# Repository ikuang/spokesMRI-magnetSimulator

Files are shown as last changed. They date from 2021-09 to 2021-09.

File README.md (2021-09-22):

# spokesMRI-magnetSimulator
 
 Matlab simulator for magnetic fields generated by 'spokes-and-hub' permanent magnet arrays as presented at ISMRM 2019 [1].
 
 To input magnet geometries and run simulator use:
 ```matlab 
 testMagnet.m
 ```
 
 We have provided [STL](stl) files for a 191 mT magnet constructed using 64 bar magnets (1/2" x 1/8" x 1") from [K&J Magnets](https://www.kjmagnetics.com/proddetail.asp?prod=B82X0).
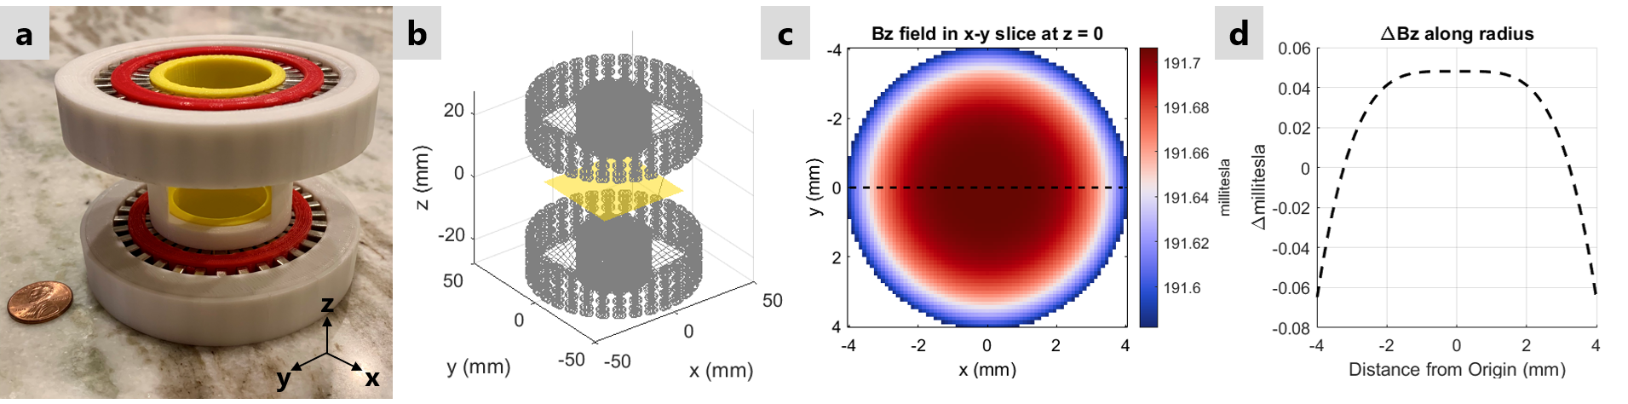
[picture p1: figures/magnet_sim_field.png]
 
 
 We use mechanical tilts from linear actuators to generate gradient fields within the magnet [2]. The actuators and their control boards were purchased from [Actuonix](https://www.actuonix.com/L12-P-Micro-Linear-Actuator-with-Position-Feedback-p/l12-p.htm). Instructions and [DXF](dxf) files for laser cutting acrylic are provided as well.
 
 
 We use an 8-channel STHV800 ultrasound h-bridge driver chip from [STMicroelectronics](https://www.st.com/en/switches-and-multiplexers/sthv800.html) to transmit/receive RF on a solenoid coil [3]. A Teensy 4.0 microcontroller sends RF pulses to the driver. We have provided a sample dithered RF pulse (centered at 8.18MHz with 100kHz bandwidth), Arduino code that controls the pulses and actuator movements, and Eagle PCB layouts for the ultrasound chip board. These files are found in the [signalChain](./signalChain) directory. We use a USB oscilloscope from Pico Technology ([PicoScope 5243D](https://www.picotech.com/oscilloscope/5000/flexible-resolution-oscilloscope)) to capture MR data at the Larmor frequency and perform filtering and downsampling in software. Pico Technology provides open source software development kits for Python and Matlab implementations (https://github.com/picotech). 
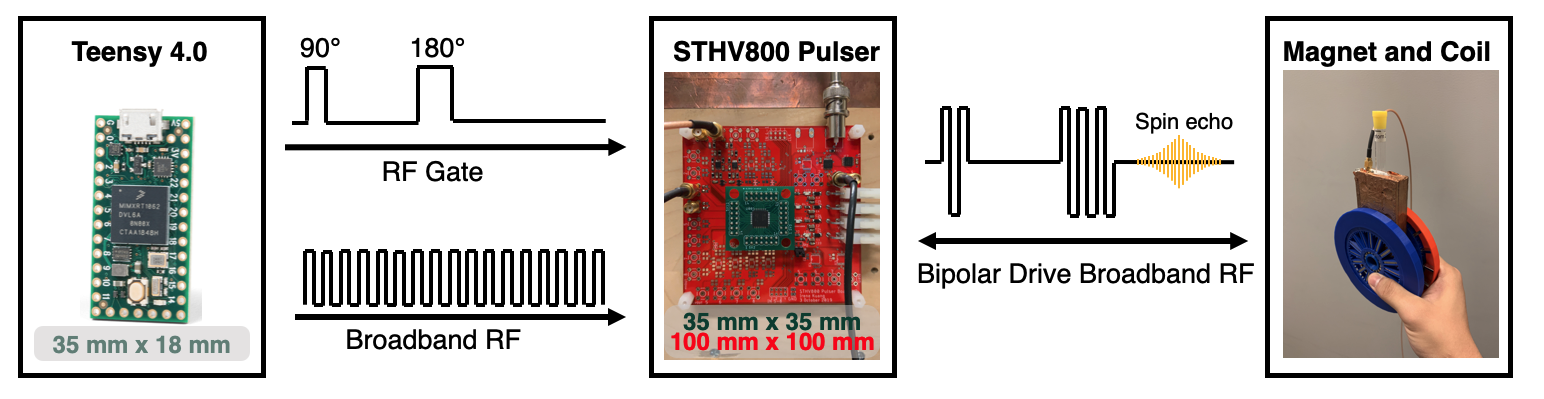
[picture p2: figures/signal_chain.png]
  

## References

[1] Kuang, I., Arango, N., Stockmann, J., Adalsteinsson, E., White, J. <em>Equivalent-Charge-Based Optimization of Spokes-and-Hub Magnets for Hand-Held and Classroom MR Imaging</em>. Proc. Intl. Soc. Mag. Reson. Med., 2019. 

[2] Kuang, I., Stockmann, J., Adalsteinsson, E., White, J. <em>Mechanical Tilt-Induced Gradient Fields for Low-Field Spokes-and-Hub MR Imagers</em>. Proc. Intl. Soc. Mag. Reson. Med., 2021. 

[3] Kuang, I., Arango, N., Stockmann, J., Adalsteinsson, E., White, J. <em>Bloch-Optimized Dithered-Ultrasound-Pulse RF for Low-Field Inhomogeneous Permanent Magnet MR Imagers</em>. Proc. Intl. Soc. Mag. Reson. Med., 2020. 
 
 Plotting functions use perceptually uniform colormaps from https://colorcet.com/

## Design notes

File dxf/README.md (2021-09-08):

# DXF files for laser cutting  
We assembled the linear actuators and magnet with three laser-cut pieces of acrylic (1/4" thick)

1/4"-20 threaded rod were used to loosly align the laser-cut pieces



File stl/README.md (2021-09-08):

# STL files for 3d printing
 
To assemble full magnet, the following pieces are required: 

* innerRing_v3.stl (Quantity: 2)
* outerRing_v2.stl (Quantity: 2)
* hub_outer_v5.stl (Quantity: 2)
* hub_middle_v1.stl (Quantity: 2)
* screw_separator_v4.stl (Quantity: 1)

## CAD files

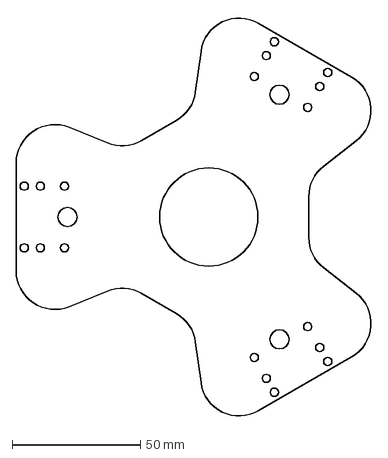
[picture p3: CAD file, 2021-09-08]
dxf/actuatorMiddle_v1.dxf
138.5 x 156.2 mm

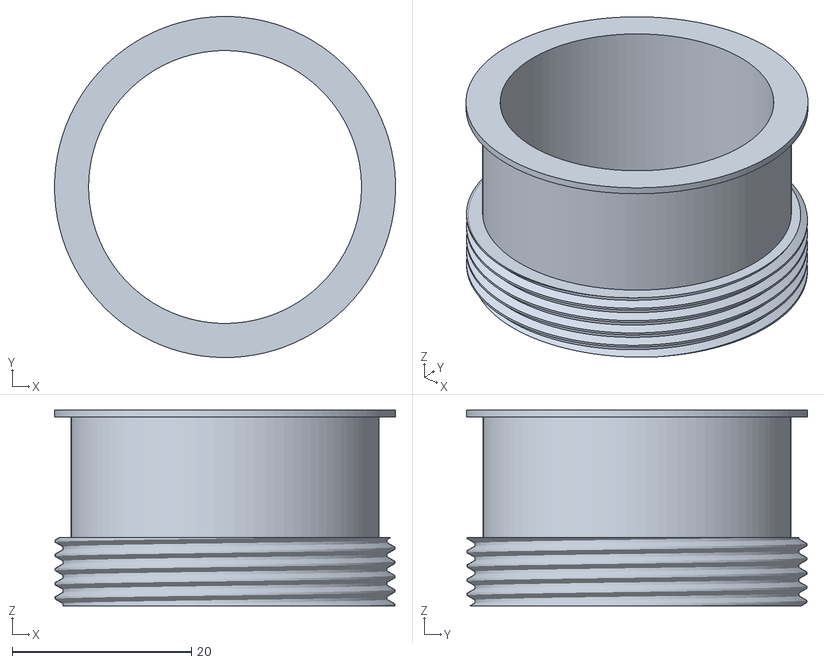
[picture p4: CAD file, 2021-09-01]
stl/innerRing_v3.stl
38.1 x 38.1 x 21.8

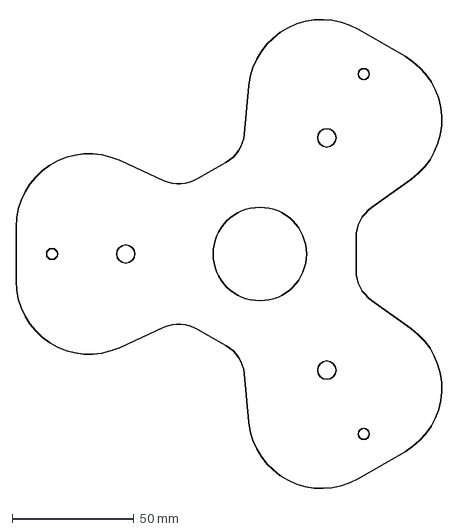
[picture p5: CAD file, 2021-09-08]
dxf/actuatorBottom_v1.dxf
175.1 x 195.1 mm

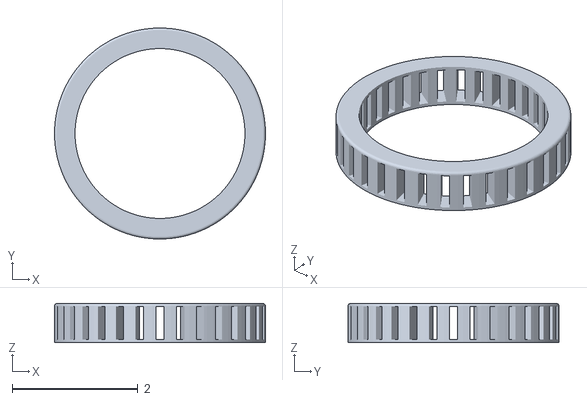
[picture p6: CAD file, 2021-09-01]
stl/hub_outer_v5.stl
3.35 x 3.35 x 0.62

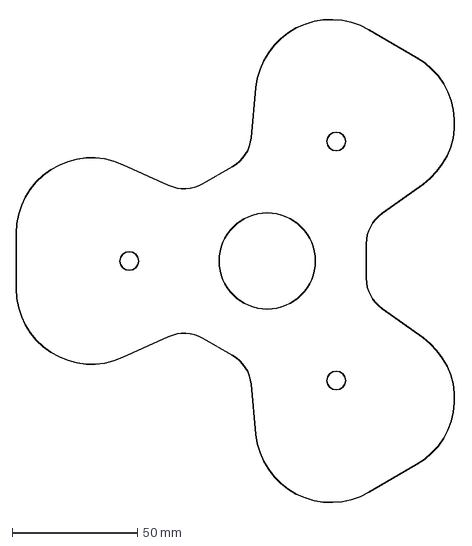
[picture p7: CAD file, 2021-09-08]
dxf/actuatorTop_v1.dxf
175.1 x 195.1 mm

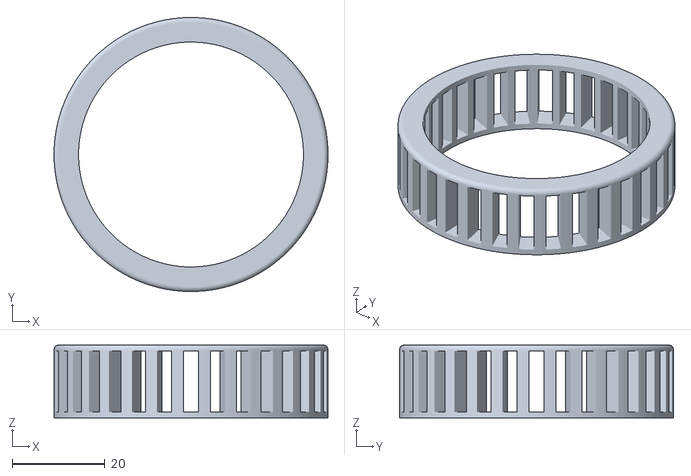
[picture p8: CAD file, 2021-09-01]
stl/hub_middle_v1.stl
59.2 x 59.2 x 15.7

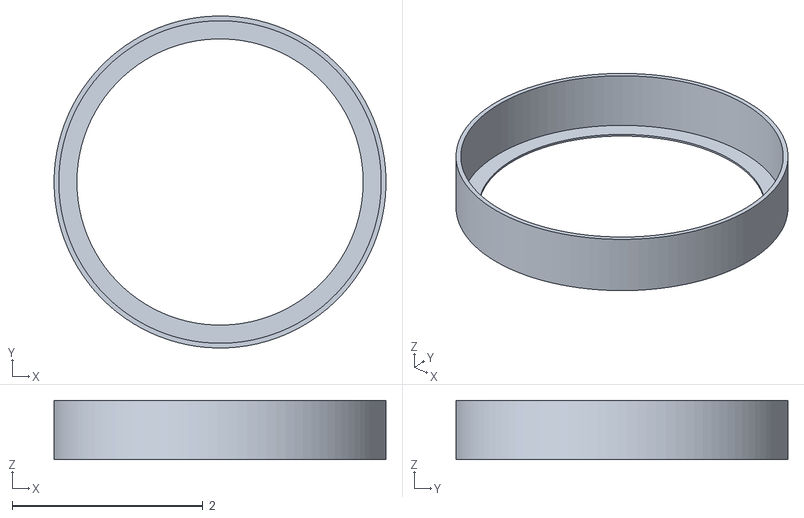
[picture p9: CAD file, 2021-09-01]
stl/outerRing_v2.stl
3.48 x 3.48 x 0.62

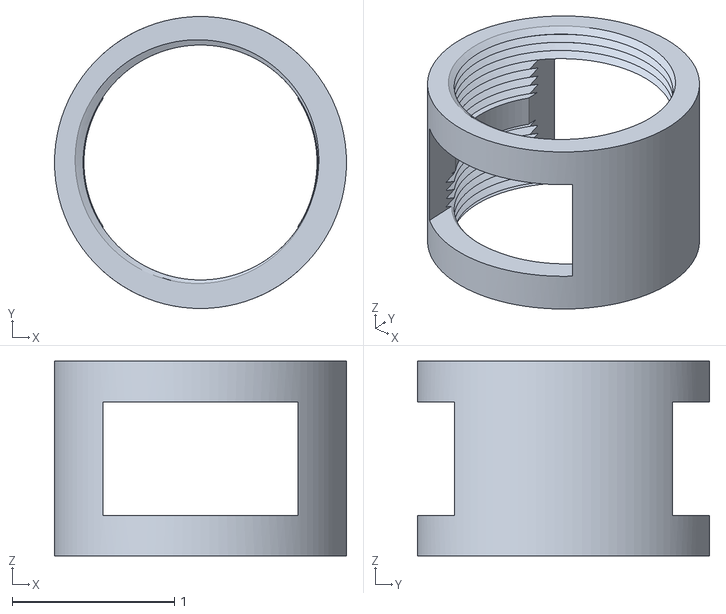
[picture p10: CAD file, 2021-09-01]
stl/screw_separator_v4.stl
1.80 x 1.80 x 1.20

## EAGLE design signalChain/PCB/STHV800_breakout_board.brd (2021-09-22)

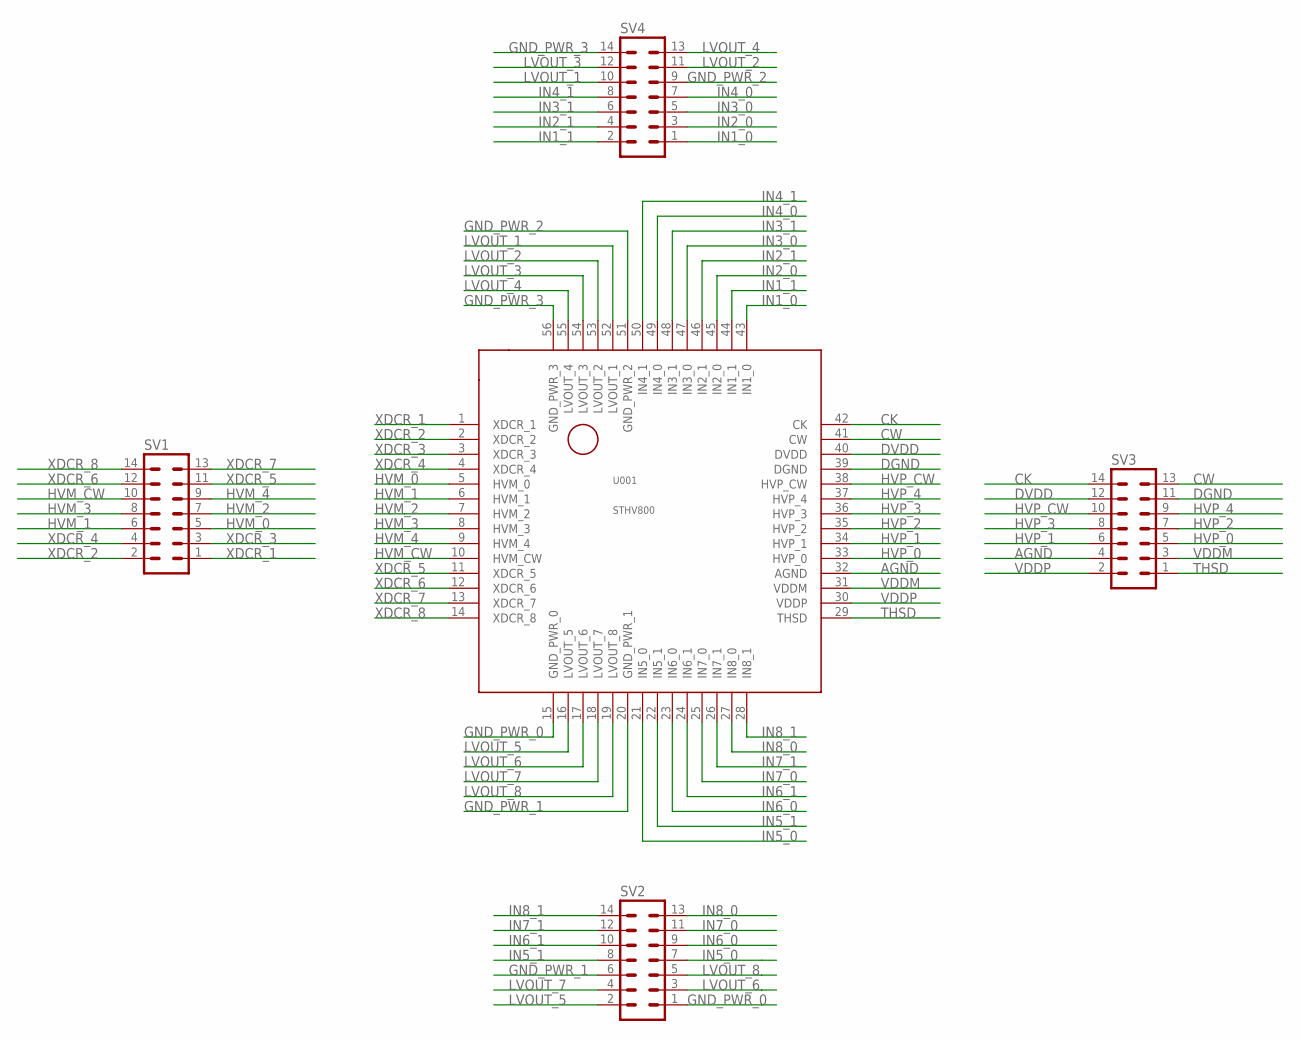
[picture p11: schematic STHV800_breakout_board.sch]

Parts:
SV1, SV2, SV3, SV4: MA07-2
U001: STHV800

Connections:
AGND: SV3.4, U001.32 (AGND)
CK: SV3.14, U001.42 (CK)
CW: SV3.13, U001.41 (CW)
DGND: SV3.11, U001.39 (DGND)
DVDD: SV3.12, U001.40 (DVDD)
GND_PWR_0: SV2.1, U001.15 (GND_PWR_0)
GND_PWR_1: SV2.6, U001.20 (GND_PWR_1)
GND_PWR_2: SV4.9, U001.51 (GND_PWR_2)
GND_PWR_3: SV4.14, U001.56 (GND_PWR_3)
HVM_0: SV1.5, U001.5 (HVM_0)
HVM_1: SV1.6, U001.6 (HVM_1)
HVM_2: SV1.7, U001.7 (HVM_2)
HVM_3: SV1.8, U001.8 (HVM_3)
HVM_4: SV1.9, U001.9 (HVM_4)
HVM_CW: SV1.10, U001.10 (HVM_CW)
HVP_0: SV3.5, U001.33 (HVP_0)
HVP_1: SV3.6, U001.34 (HVP_1)
HVP_2: SV3.7, U001.35 (HVP_2)
HVP_3: SV3.8, U001.36 (HVP_3)
HVP_4: SV3.9, U001.37 (HVP_4)
HVP_CW: SV3.10, U001.38 (HVP_CW)
IN1_0: SV4.1, U001.43 (IN1_0)
IN1_1: SV4.2, U001.44 (IN1_1)
IN2_0: SV4.3, U001.45 (IN2_0)
IN2_1: SV4.4, U001.46 (IN2_1)
IN3_0: SV4.5, U001.47 (IN3_0)
IN3_1: SV4.6, U001.48 (IN3_1)
IN4_0: SV4.7, U001.49 (IN4_0)
IN4_1: SV4.8, U001.50 (IN4_1)
IN5_0: SV2.7, U001.21 (IN5_0)
IN5_1: SV2.8, U001.22 (IN5_1)
IN6_0: SV2.9, U001.23 (IN6_0)
IN6_1: SV2.10, U001.24 (IN6_1)
IN7_0: SV2.11, U001.25 (IN7_0)
IN7_1: SV2.12, U001.26 (IN7_1)
IN8_0: SV2.13, U001.27 (IN8_0)
IN8_1: SV2.14, U001.28 (IN8_1)
LVOUT_1: SV4.10, U001.52 (LVOUT_1)
LVOUT_2: SV4.11, U001.53 (LVOUT_2)
LVOUT_3: SV4.12, U001.54 (LVOUT_3)
LVOUT_4: SV4.13, U001.55 (LVOUT_4)
LVOUT_5: SV2.2, U001.16 (LVOUT_5)
LVOUT_6: SV2.3, U001.17 (LVOUT_6)
LVOUT_7: SV2.4, U001.18 (LVOUT_7)
LVOUT_8: SV2.5, U001.19 (LVOUT_8)
THSD: SV3.1, U001.29 (THSD)
VDDM: SV3.3, U001.31 (VDDM)
VDDP: SV3.2, U001.30 (VDDP)
XDCR_1: SV1.1, U001.1 (XDCR_1)
XDCR_2: SV1.2, U001.2 (XDCR_2)
XDCR_3: SV1.3, U001.3 (XDCR_3)
XDCR_4: SV1.4, U001.4 (XDCR_4)
XDCR_5: SV1.11, U001.11 (XDCR_5)
XDCR_6: SV1.12, U001.12 (XDCR_6)
XDCR_7: SV1.13, U001.13 (XDCR_7)
XDCR_8: SV1.14, U001.14 (XDCR_8)

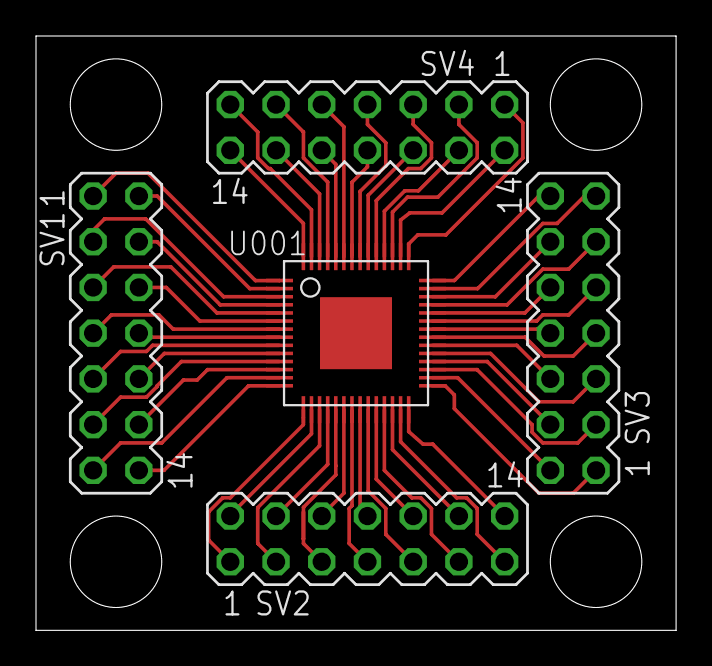
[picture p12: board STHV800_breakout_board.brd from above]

Board: 2 copper layers, 35.6 x 33.0 mm, 5 parts (0 on the bottom side), 56 nets.

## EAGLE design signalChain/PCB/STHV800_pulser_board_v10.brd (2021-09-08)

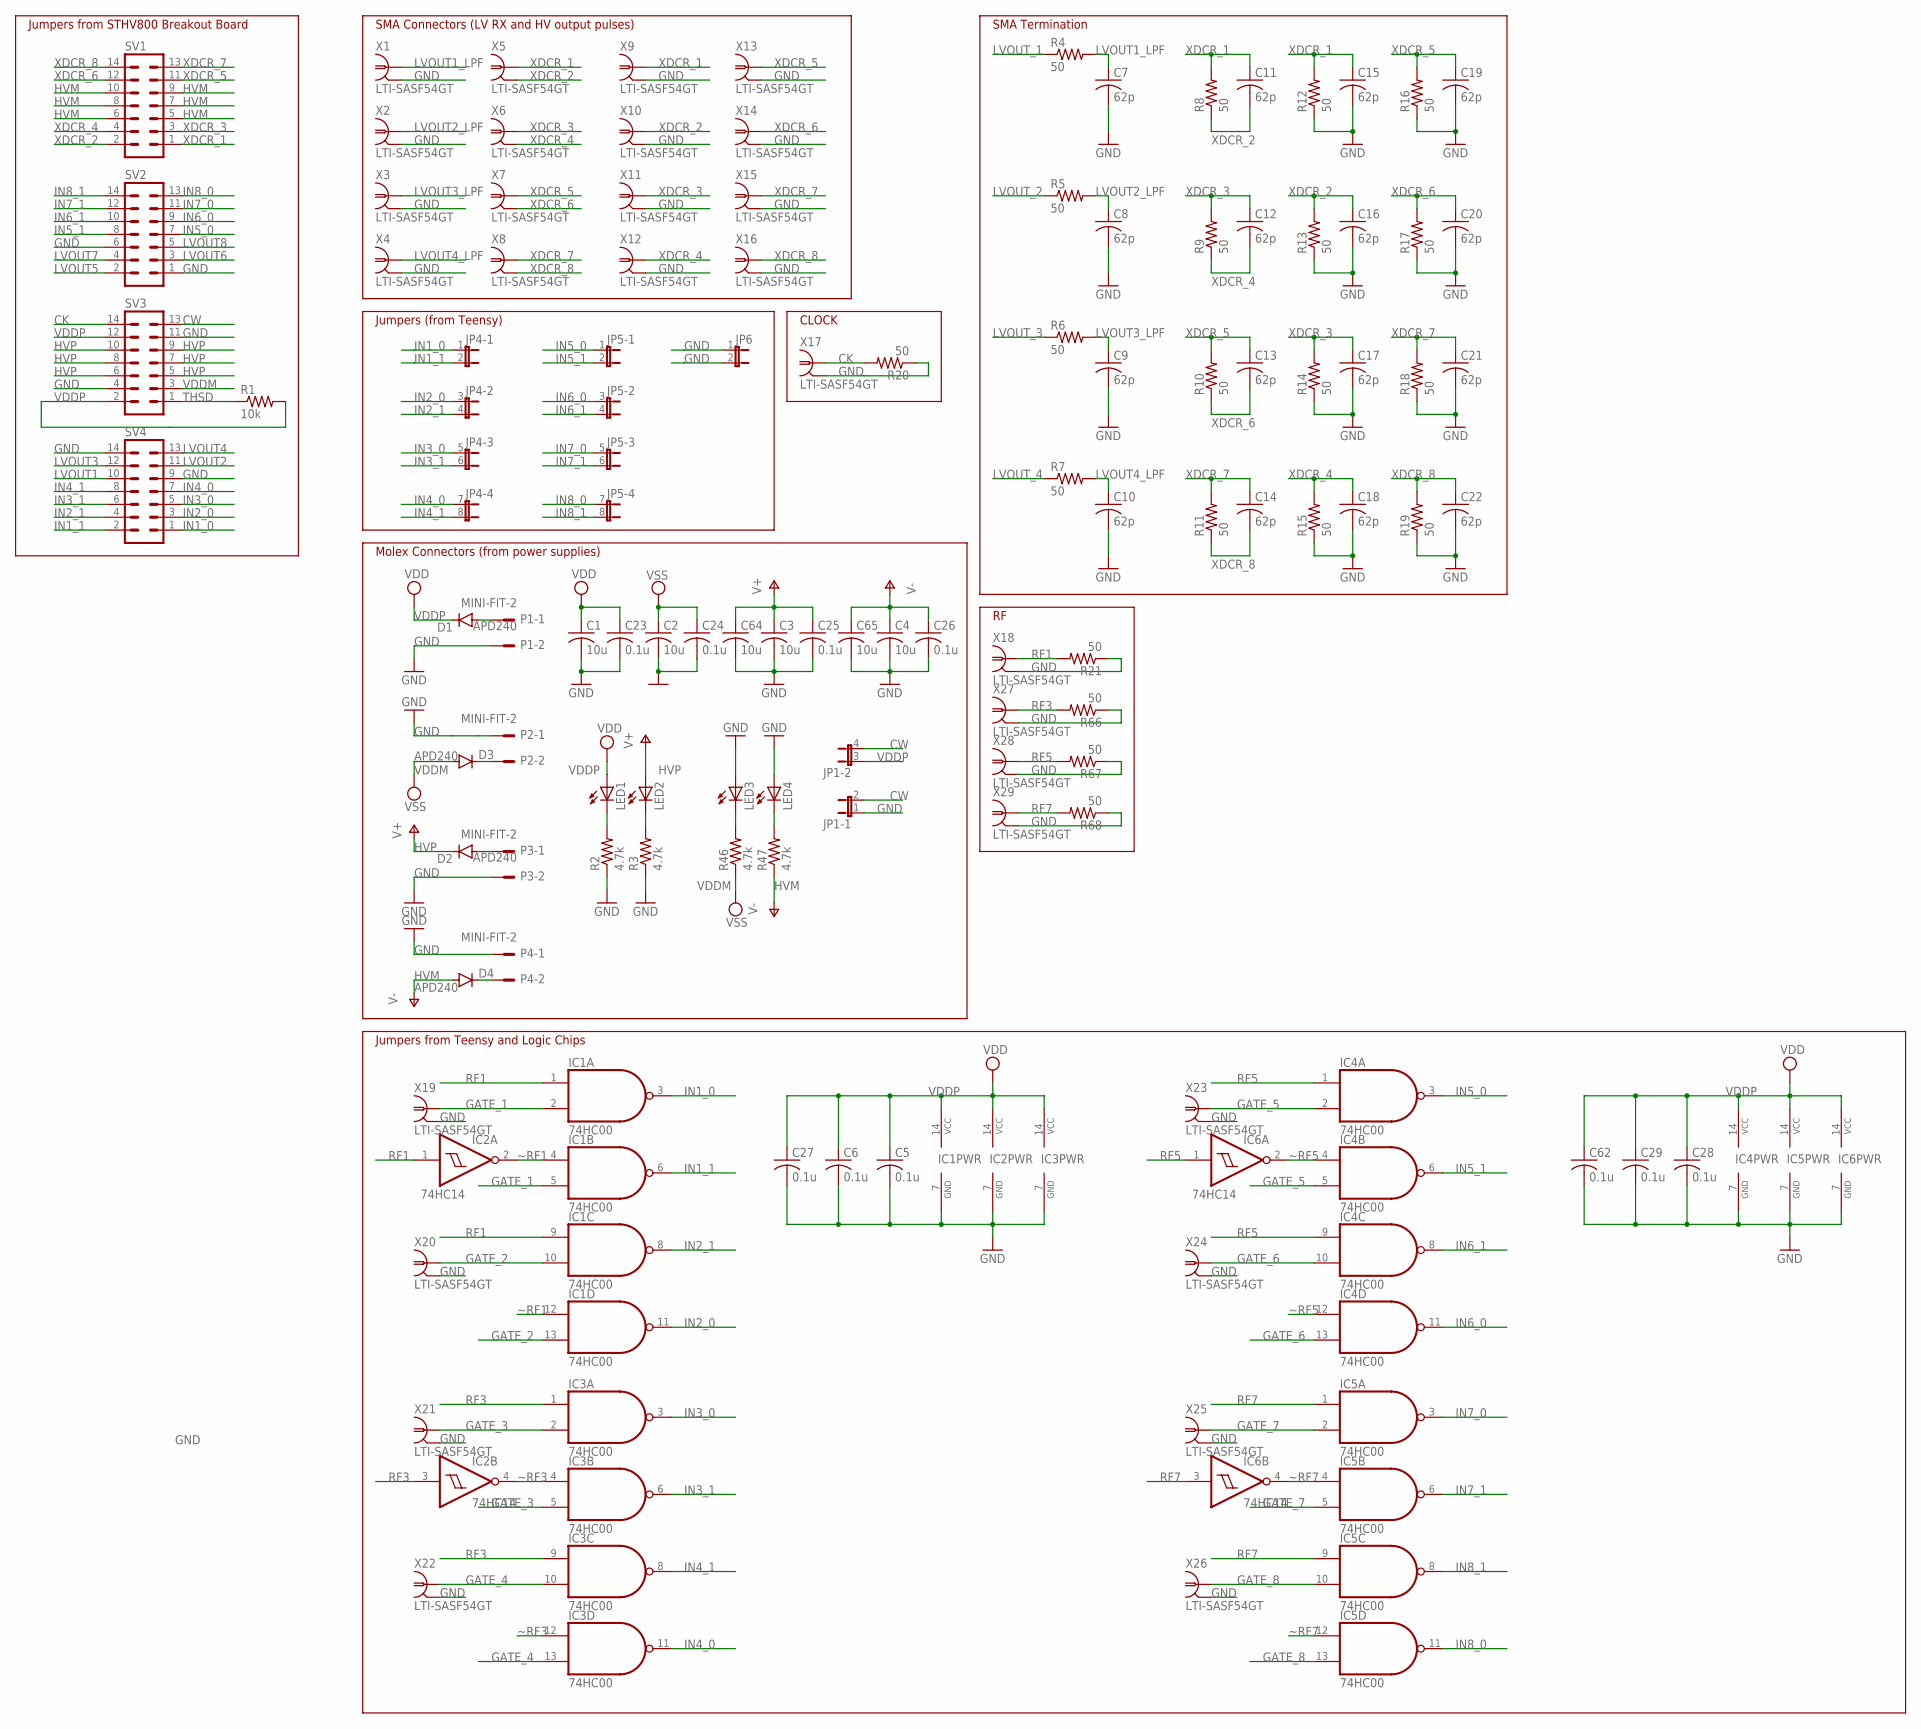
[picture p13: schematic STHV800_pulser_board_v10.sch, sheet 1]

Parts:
C1, C2: 10u; C1206
C3, C4, C64, C65: 10u; C1210
C5, C6, C23, C24, C25, C26, C27, C28, C29, C62: 0.1u; C0805
C7, C8, C9, C10, C11, C12, C13, C14, C15, C16, C17, C18, C19, C20, C21, C22: 62p; C0805
D1, D2, D3, D4: APD240; SOD-123_MINI-SMA
IC1, IC3, IC4, IC5: 74HC00; TSSOP14
IC2, IC6: 74HC14; TSSOP14
JP1: JP2QE; JP2Q
JP4, JP5: JP4QE; JP4Q
JP6: JP1E; JP1
LED1, LED2, LED3, LED4: LEDSMT1206; 1206
P1, P2, P3, P4: MINI-FIT-2; CON-MOLEX-MINI-FIT_39-30-?02?
R1: 10k; R0805
R2, R3, R46, R47: 4.7k; R0805
R4, R5, R6, R7, R8, R9, R10, R11, R12, R13, R14, R15, R16, R17, R18, R19: 50; R1206
R20, R21, R66, R67, R68: 50; R0805
SV1, SV2, SV3, SV4: MA07-2
X1, X2, X3, X4, X5, X6, X7, X8, X9, X10, X11, X12, X13, X14, X15, X16, X17, X18, X19, X20, X21, X22, X23, X24, X25, X26, X27, X28, X29: LTI-SASF54GT

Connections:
CK: R20.2, SV3.14, X17.1
CW: JP1.2, JP1.4 (2), SV3.13
GATE_1: IC1.2 (I1), IC1.5 (I1), X19.1
GATE_2: IC1.10 (I1), IC1.13 (I1), X20.1
GATE_3: IC3.2 (I1), IC3.5 (I1), X21.1
GATE_4: IC3.10 (I1), IC3.13 (I1), X22.1
GATE_5: IC4.2 (I1), IC4.5 (I1), X23.1
GATE_6: IC4.10 (I1), IC4.13 (I1), X24.1
GATE_7: IC5.2 (I1), IC5.5 (I1), X25.1
GATE_8: IC5.10 (I1), IC5.13 (I1), X26.1
GND: C1.2, C2.2, C3.2, C4.2, C5.2, C6.2, C7.2, C8.2, C9.2, C10.2, C15.2, C16.2, C17.2, C18.2, C19.2, C20.2, C21.2, C22.2, C23.2, C24.2, C25.2, C26.2, C27.2, C28.2, C29.2, C62.2, C64.2, C65.2, IC1.7 (GND), IC2.7 (GND), IC3.7 (GND), IC4.7 (GND), IC5.7 (GND), IC6.7 (GND), JP1.1, JP6.1, JP6.2, LED3.A, LED4.A, P1.2, P2.1, P3.2, P4.1, R2.1, R3.1, R12.1, R13.1, R14.1, R15.1, R16.1, R17.1, R18.1, R19.1, R20.1, R21.1, R66.1, R67.1, R68.1, SV2.1, SV2.6, SV3.4, SV3.11, SV4.9, SV4.14, X1.2, X1.3 (2), X1.4 (2), X1.5 (2), X2.2, X2.3 (2), X2.4 (2), X2.5 (2), X3.2, X3.3 (2), X3.4 (2), X3.5 (2), X4.2, X4.3 (2), X4.4 (2), X4.5 (2), X9.2, X9.3 (2), X9.4 (2), X9.5 (2), X10.2, X10.3 (2), X10.4 (2), X10.5 (2), X11.2, X11.3 (2), X11.4 (2), X11.5 (2), X12.2, X12.3 (2), X12.4 (2), X12.5 (2), X13.2, X13.3 (2), X13.4 (2), X13.5 (2), X14.2, X14.3 (2), X14.4 (2), X14.5 (2), X15.2, X15.3 (2), X15.4 (2), X15.5 (2), X16.2, X16.3 (2), X16.4 (2), X16.5 (2), X17.2, X17.3 (2), X17.4 (2), X17.5 (2), X18.2, X18.3 (2), X18.4 (2), X18.5 (2), X19.2, X19.3 (2), X19.4 (2), X19.5 (2), X20.2, X20.3 (2), X20.4 (2), X20.5 (2), X21.2, X21.3 (2), X21.4 (2), X21.5 (2), X22.2, X22.3 (2), X22.4 (2), X22.5 (2), X23.2, X23.3 (2), X23.4 (2), X23.5 (2), X24.2, X24.3 (2), X24.4 (2), X24.5 (2), X25.2, X25.3 (2), X25.4 (2), X25.5 (2), X26.2, X26.3 (2), X26.4 (2), X26.5 (2), X27.2, X27.3 (2), X27.4 (2), X27.5 (2), X28.2, X28.3 (2), X28.4 (2), X28.5 (2), X29.2, X29.3 (2), X29.4 (2), X29.5 (2); also elsewhere on the board
HVM: C4.1, C26.1, C65.1, D4.A, R47.1, SV1.5, SV1.6, SV1.7, SV1.8, SV1.9, SV1.10
HVP: C3.1, C25.1, C64.1, D2.C, LED2.A, SV3.5, SV3.6, SV3.7, SV3.8, SV3.9, SV3.10
HVP_1: D2.A, P3.1
IN1_0: IC1.3 (O), JP4.1, SV4.1
IN1_1: IC1.6 (O), JP4.2, SV4.2
IN2_0: IC1.11 (O), JP4.3 (1), SV4.3
IN2_1: IC1.8 (O), JP4.4 (2), SV4.4
IN3_0: IC3.3 (O), JP4.5 (1), SV4.5
IN3_1: IC3.6 (O), JP4.6 (2), SV4.6
IN4_0: IC3.11 (O), JP4.7 (1), SV4.7
IN4_1: IC3.8 (O), JP4.8 (2), SV4.8
IN5_0: IC4.3 (O), JP5.1, SV2.7
IN5_1: IC4.6 (O), JP5.2, SV2.8
IN6_0: IC4.11 (O), JP5.3 (1), SV2.9
IN6_1: IC4.8 (O), JP5.4 (2), SV2.10
IN7_0: IC5.3 (O), JP5.5 (1), SV2.11
IN7_1: IC5.6 (O), JP5.6 (2), SV2.12
IN8_0: IC5.11 (O), JP5.7 (1), SV2.13
IN8_1: IC5.8 (O), JP5.8 (2), SV2.14
LVOUT1: SV4.10; also elsewhere on the board
LVOUT1_LPF: C7.1, R4.2, X1.1
LVOUT2: SV4.11; also elsewhere on the board
LVOUT2_LPF: C8.1, R5.2, X2.1
LVOUT3: SV4.12; also elsewhere on the board
LVOUT3_LPF: C9.1, R6.2, X3.1
LVOUT4: SV4.13; also elsewhere on the board
LVOUT4_LPF: C10.1, R7.2, X4.1
LVOUT5: SV2.2; also elsewhere on the board
LVOUT6: SV2.3; also elsewhere on the board
LVOUT7: SV2.4; also elsewhere on the board
LVOUT8: SV2.5; also elsewhere on the board
LVOUT_1: R4.1; also elsewhere on the board
LVOUT_2: R5.1; also elsewhere on the board
LVOUT_3: R6.1; also elsewhere on the board
LVOUT_4: R7.1; also elsewhere on the board
unnamed: LED1.C, R2.2
unnamed: LED2.C, R3.2
unnamed: LED3.C, R46.2
unnamed: LED4.C, R47.2
unnamed: D3.C, P2.2
unnamed: D4.C, P4.2
RF1: IC1.1 (I0), IC1.9 (I0), IC2.1 (I), R21.2, X18.1
RF3: IC2.3 (I), IC3.1 (I0), IC3.9 (I0), R66.2, X27.1
RF5: IC4.1 (I0), IC4.9 (I0), IC6.1 (I), R67.2, X28.1
RF7: IC5.1 (I0), IC5.9 (I0), IC6.3 (I), R68.2, X29.1
THSD: R1.1, SV3.1
VDDM: C2.1, C24.1, D3.A, R46.1, SV3.3; also elsewhere on the board
VDDP: C1.1, C5.1, C6.1, C23.1, C27.1, C28.1, C29.1, C62.1, D1.C, IC1.14 (VCC), IC2.14 (VCC), IC3.14 (VCC), IC4.14 (VCC), IC5.14 (VCC), IC6.14 (VCC), JP1.3 (1), LED1.A, R1.2, SV3.2, SV3.12; also elsewhere on the board
VDDP_1: D1.A, P1.1
XDCR_1: C11.1, C15.1, R8.2, R12.2, SV1.1, X5.1, X9.1
XDCR_2: C11.2, C16.1, R8.1, R13.2, SV1.2, X5.2, X5.3 (2), X5.4 (2), X5.5 (2), X10.1
XDCR_3: C12.1, C17.1, R9.2, R14.2, SV1.3, X6.1, X11.1
XDCR_4: C12.2, C18.1, R9.1, R15.2, SV1.4, X6.2, X6.3 (2), X6.4 (2), X6.5 (2), X12.1
XDCR_5: C13.1, C19.1, R10.2, R16.2, SV1.11, X7.1, X13.1
XDCR_6: C13.2, C20.1, R10.1, R17.2, SV1.12, X7.2, X7.3 (2), X7.4 (2), X7.5 (2), X14.1
XDCR_7: C14.1, C21.1, R11.2, R18.2, SV1.13, X8.1, X15.1
XDCR_8: C14.2, C22.1, R11.1, R19.2, SV1.14, X8.2, X8.3 (2), X8.4 (2), X8.5 (2), X16.1
~RF1: IC1.4 (I0), IC1.12 (I0), IC2.2 (O)
~RF3: IC2.4 (O), IC3.4 (I0), IC3.12 (I0)
~RF5: IC4.4 (I0), IC4.12 (I0), IC6.2 (O)
~RF7: IC5.4 (I0), IC5.12 (I0), IC6.4 (O)

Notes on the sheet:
SMA Connectors (LV RX and HV output pulses)
Jumpers (from Teensy)
Molex Connectors (from power supplies)
CLOCK
Jumpers from Teensy and Logic Chips
Jumpers from STHV800 Breakout Board
SMA Termination

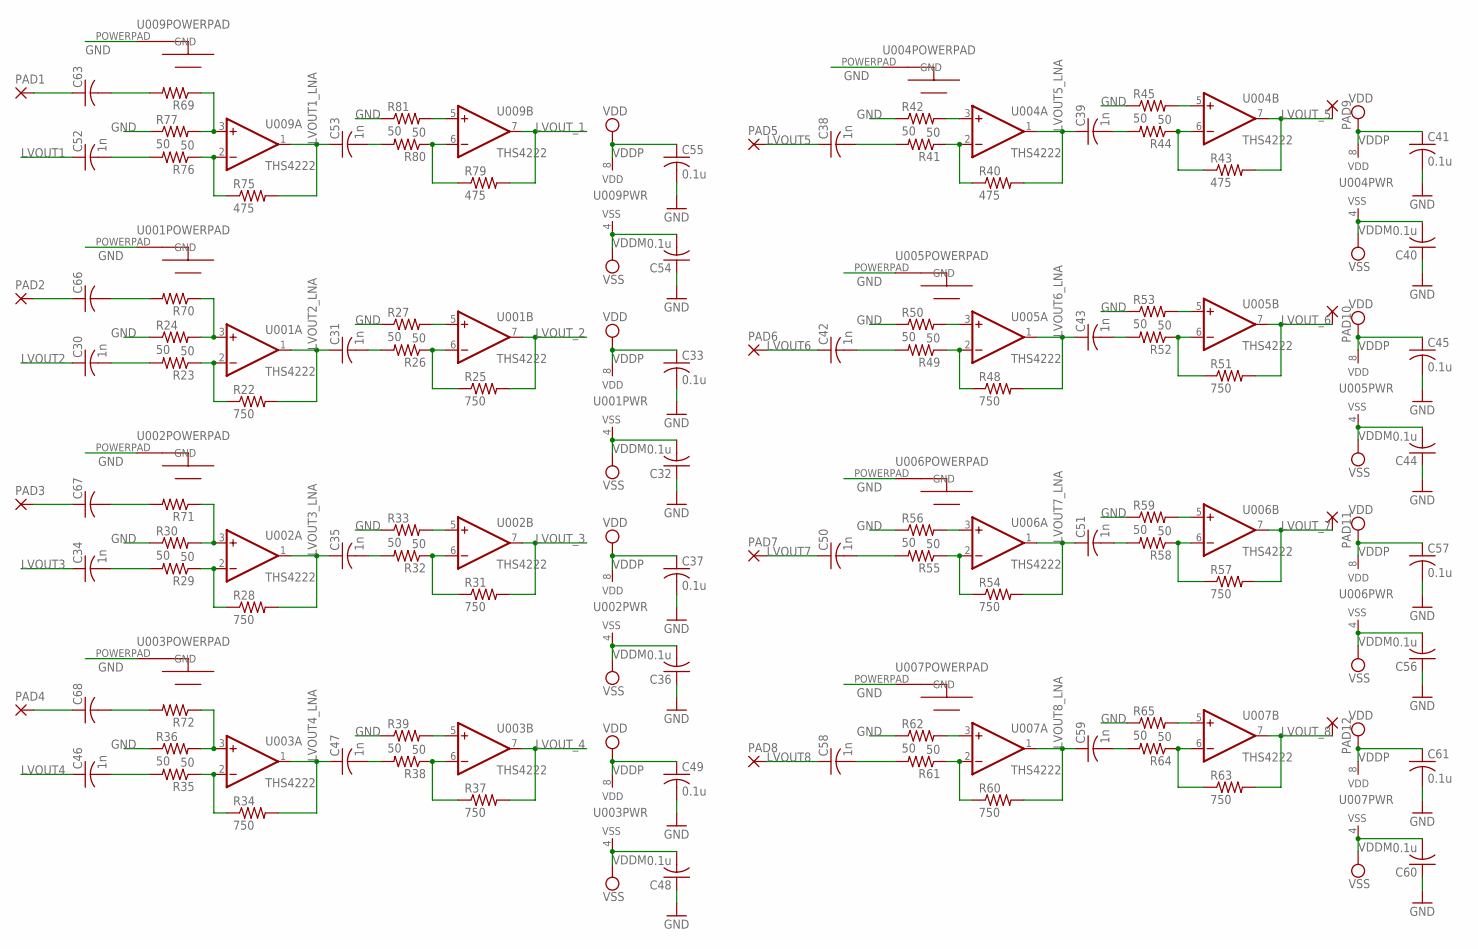
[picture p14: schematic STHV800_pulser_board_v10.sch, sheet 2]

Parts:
C30, C31, C34, C35, C38, C39, C42, C43, C46, C47, C50, C51, C52, C53, C58, C59: 1n; C0805
C32, C33, C36, C37, C40, C41, C44, C45, C48, C49, C54, C55, C56, C57, C60, C61: 0.1u; C0805
C63, C66, C67, C68: C-USC0805; C0805
PAD1, PAD2, PAD3, PAD4, PAD5, PAD6, PAD7, PAD8, PAD9, PAD10, PAD11, PAD12: 1,6/0,8
R22, R25, R28, R31, R34, R37, R48, R51, R54, R57, R60, R63: 750; R0805
R23, R24, R26, R27, R29, R30, R32, R33, R35, R36, R38, R39, R41, R42, R44, R45, R49, R50, R52, R53, R55, R56, R58, R59, R61, R62, R64, R65, R76, R77, R80, R81: 50; R0805
R40, R43, R75, R79: 475; R0805
R69, R70, R71, R72: R-US_R0805; R0805
U001, U002, U003, U004, U005, U006, U007, U009: THS4222; SSOP08-POWERPAD

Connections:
GND: C32.1, C33.2, C36.1, C37.2, C40.1, C41.2, C44.1, C45.2, C48.1, C49.2, C54.1, C55.2, C56.1, C57.2, C60.1, C61.2, R24.1, R27.1, R30.1, R33.1, R36.1, R39.1, R42.1, R45.1, R50.1, R53.1, R56.1, R59.1, R62.1, R65.1, R77.1, R81.1, U001.POWERPAD (GND), U002.POWERPAD (GND), U003.POWERPAD (GND), U004.POWERPAD (GND), U005.POWERPAD (GND), U006.POWERPAD (GND), U007.POWERPAD (GND), U009.POWERPAD (GND); also elsewhere on the board
LVOUT1: C52.1; also elsewhere on the board
LVOUT1_LNA: C53.1, R75.2, U009.1 (OUT)
LVOUT2: C30.1; also elsewhere on the board
LVOUT2_LNA: C31.1, R22.2, U001.1 (OUT)
LVOUT3: C34.1; also elsewhere on the board
LVOUT3_LNA: C35.1, R28.2, U002.1 (OUT)
LVOUT4: C46.1; also elsewhere on the board
LVOUT4_LNA: C47.1, R34.2, U003.1 (OUT)
LVOUT5: C38.1, PAD5.1; also elsewhere on the board
LVOUT5_LNA: C39.1, R40.2, U004.1 (OUT)
LVOUT6: C42.1, PAD6.1; also elsewhere on the board
LVOUT6_LNA: C43.1, R48.2, U005.1 (OUT)
LVOUT7: C50.1, PAD7.1; also elsewhere on the board
LVOUT7_LNA: C51.1, R54.2, U006.1 (OUT)
LVOUT8: C58.1, PAD8.1; also elsewhere on the board
LVOUT8_LNA: C59.1, R60.2, U007.1 (OUT)
LVOUT_1: R79.2, U009.7 (OUT); also elsewhere on the board
LVOUT_2: R25.2, U001.7 (OUT); also elsewhere on the board
LVOUT_3: R31.2, U002.7 (OUT); also elsewhere on the board
LVOUT_4: R37.2, U003.7 (OUT); also elsewhere on the board
LVOUT_5: PAD9.1, R43.2, U004.7 (OUT)
LVOUT_6: PAD10.1, R51.2, U005.7 (OUT)
LVOUT_7: PAD11.1, R57.2, U006.7 (OUT)
LVOUT_8: PAD12.1, R63.2, U007.7 (OUT)
unnamed: R25.1, R26.1, U001.6 (-IN)
unnamed: R24.2, R70.1, U001.3 (+IN)
unnamed: R22.1, R23.1, U001.2 (-IN)
unnamed: C30.2, R23.2
unnamed: C31.2, R26.2
unnamed: R27.2, U001.5 (+IN)
unnamed: R31.1, R32.1, U002.6 (-IN)
unnamed: R30.2, R71.1, U002.3 (+IN)
unnamed: R43.1, R44.1, U004.6 (-IN)
unnamed: R42.2, U004.3 (+IN)
unnamed: R40.1, R41.1, U004.2 (-IN)
unnamed: C38.2, R41.2
unnamed: C39.2, R44.2
unnamed: R45.2, U004.5 (+IN)
unnamed: R51.1, R52.1, U005.6 (-IN)
unnamed: R28.1, R29.1, U002.2 (-IN)
unnamed: C34.2, R29.2
unnamed: C35.2, R32.2
unnamed: R33.2, U002.5 (+IN)
unnamed: R37.1, R38.1, U003.6 (-IN)
unnamed: R36.2, R72.1, U003.3 (+IN)
unnamed: R34.1, R35.1, U003.2 (-IN)
unnamed: C46.2, R35.2
unnamed: C47.2, R38.2
unnamed: R39.2, U003.5 (+IN)
unnamed: R50.2, U005.3 (+IN)
unnamed: R48.1, R49.1, U005.2 (-IN)
unnamed: C42.2, R49.2
unnamed: C43.2, R52.2
unnamed: R53.2, U005.5 (+IN)
unnamed: R57.1, R58.1, U006.6 (-IN)
unnamed: R56.2, U006.3 (+IN)
unnamed: R54.1, R55.1, U006.2 (-IN)
unnamed: C50.2, R55.2
unnamed: C51.2, R58.2
unnamed: R59.2, U006.5 (+IN)
unnamed: R63.1, R64.1, U007.6 (-IN)
unnamed: R62.2, U007.3 (+IN)
unnamed: R60.1, R61.1, U007.2 (-IN)
unnamed: C58.2, R61.2
unnamed: C59.2, R64.2
unnamed: R65.2, U007.5 (+IN)
unnamed: C63.2, R69.2
unnamed: C67.2, R71.2
unnamed: C66.2, R70.2
unnamed: C68.2, R72.2
unnamed: R79.1, R80.1, U009.6 (-IN)
unnamed: R69.1, R77.2, U009.3 (+IN)
unnamed: R75.1, R76.1, U009.2 (-IN)
unnamed: C52.2, R76.2
unnamed: C53.2, R80.2
unnamed: R81.2, U009.5 (+IN)
TEST_VIA_1: C63.1, PAD1.1
TEST_VIA_2: C66.1, PAD2.1
TEST_VIA_3: C67.1, PAD3.1
TEST_VIA_4: C68.1, PAD4.1
VDDM: C32.2, C36.2, C40.2, C44.2, C48.2, C54.2, C56.2, C60.2, U001.4 (VSS), U002.4 (VSS), U003.4 (VSS), U004.4 (VSS), U005.4 (VSS), U006.4 (VSS), U007.4 (VSS), U009.4 (VSS); also elsewhere on the board
VDDP: C33.1, C37.1, C41.1, C45.1, C49.1, C55.1, C57.1, C61.1, U001.8 (VDD), U002.8 (VDD), U003.8 (VDD), U004.8 (VDD), U005.8 (VDD), U006.8 (VDD), U007.8 (VDD), U009.8 (VDD); also elsewhere on the board

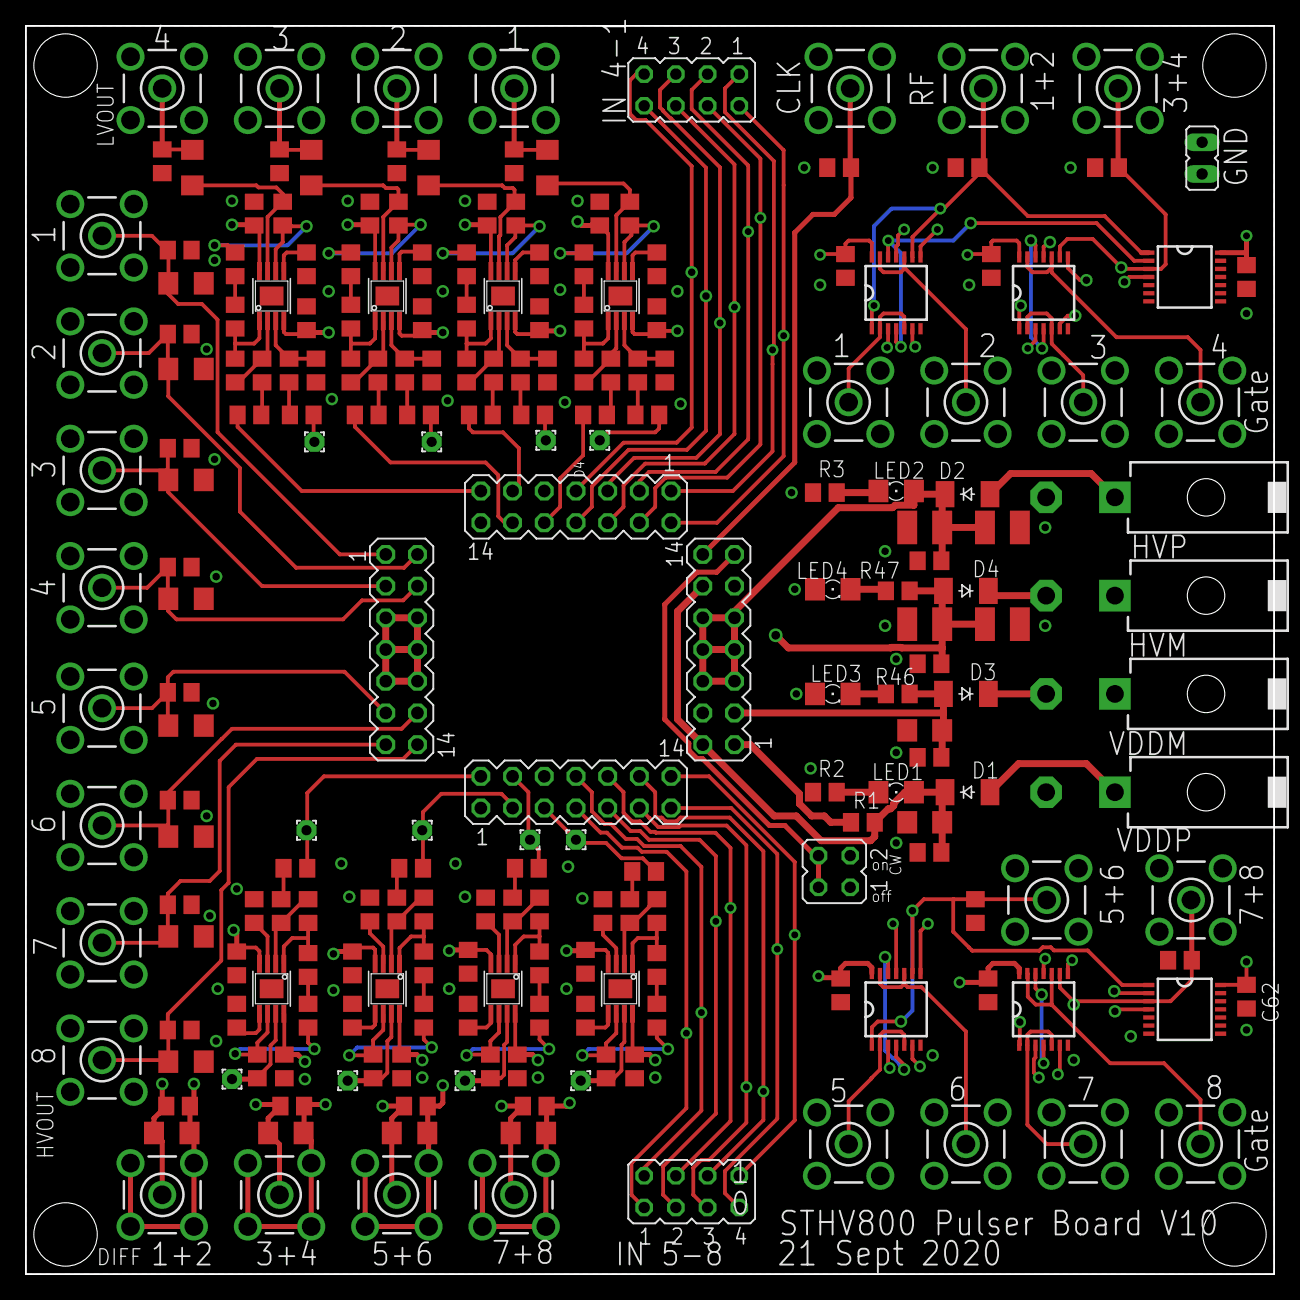
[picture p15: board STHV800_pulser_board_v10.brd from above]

Board: 4 copper layers, 100.0 x 100.0 mm, 221 parts (0 on the bottom side), 140 nets.

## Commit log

2021-09-01 magnet picture
2021-09-01 added 3d print STLs
    [hub_middle_v1.stl, hub_outer_v5.stl, innerRing_v3.stl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]
2021-09-08 added dxf files for laser cutting
    [actuatorBottom_v1.dxf, actuatorMiddle_v1.dxf, actuatorTop_v1.dxf]
2021-09-08 teensy code for RF and linear actuator control
2021-09-08 pcb files for ultrasound signal chain
    [STHV800_pulser_board_v10.brd, STHV800_pulser_board_v10.sch]
2021-09-08 code for generating RF and controlling linear actuators
2021-09-22 sthv breakout board pcb files
    [STHV800_breakout_board.brd, STHV800_breakout_board.sch]
2021-09-22 signal chain PCB gerber files
